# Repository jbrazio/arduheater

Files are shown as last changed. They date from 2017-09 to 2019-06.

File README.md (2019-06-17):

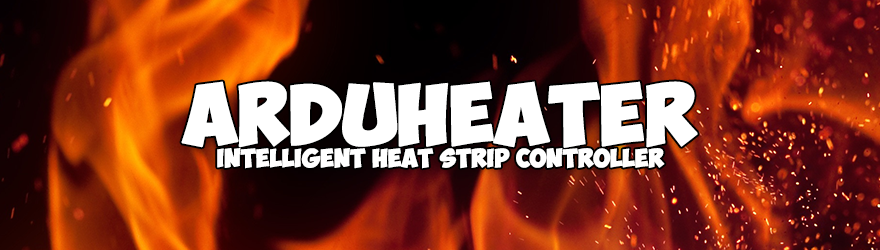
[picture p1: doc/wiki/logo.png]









# Arduheater
Arduheater is a full open source intelligent heat strip controller for astronomy usage.

# Motivation
Controlling dew is a big thing if you really intent to do astronomy all year around.
This project will allow you to build a four channel intelligent heat strip contoller for less than 10€.

# Design Goals

## 1. Remotely controllable
This was a very important part of the design, most heat controllers, specially the DIY ones, rely on the PWM signal for each channel being manually adjusted by means of a potentiometer. This either requires the user to be near the device tweeking it or to set it to a temperature that may be higher than the one really needed thus completely trashing efficiency. Arduheater uses a serial connection so you can use any USB-Serial-TTL dongle to adjust it's settings either you're 2 or 2000 meters away.

## 2. Efficient energy usage
Manual adjusted heater will either require the user to be tweeking it or they will wast more energy than necessary due to the general tendency to use a higher that required setpoint, this is valid for any PWM or bang-bang style controllers. Arduheater uses a temperature sensor (DHT22) to measure basic environmental properties such as temperature and humidity, knowing them both makes the calculation of the dew point[1] possible. Arduheater also has a temperature sensor (NTC) for each heating strip, allowing the micro-controller to have a rough estimation of the temperature the equipment is at; it will be a rough estimation because we are really interested on the lenses surface temperature but we are actually measuring the heat strip temperature, to mitigate this, Arduheater allows the user to set specific offsets per heating strip.

Arduheater uses a PID controller[2] to efficiently manage the energy so only the required amount of energy to maintain a temperature setpoint is delivered to the heating strip. This is possible due the usage of a PWM signal while driving the outputs; the delta between the environmental dew point (plus offset, i.e. setpoint) and the heating strip temperature will make the micro-controller output a PID-calculated PWM signal until this delta reaches zero. In practical terms if a 12V heating strip full on consumes 12W of power (1A) it may be possible for it to use only 1W or even less to keep the equipment above dewpoint and the power usage will be automatically updated during the night as conditions vary, so the system will be always using the least amount of power to keep the dew away.

[1] Dew point is that dreadful threshold at which water condensation starts to happen on the lenses/equipment.

[2] A proportional–integral–derivative controller (PID controller) is a control loop feedback mechanism (controller) commonly used in industrial control systems.

## 3. Builder friendly
Using off-the-shelf components such as the Arduino Nano and easily available parts Arduheater is aimed to be build by anyone with a soldering iron and some patience, no degree in electronics required.

## 4. Multiple independent channels
Each of the four outputs have independent controls such as offset, min and max output power and of course the three main properties of the PID controller (Kp, Ki and Kd).

# Hardware
It was built on top of a standard ATmega 328 Arduino such as UNO, Pro or Nano; currently it does not support the Mega or any other ARM based board.

## BOM

Qty  | Value     | Device              | Size   | Package
---: | :-------- | :------------------ | :----- | :------
1    | Nano 328P | Arduino             |        |
1    | 10uF      | Capacitor Polarized | "Ø5x11 | THT
1    | AM2320    | Probe               |        | THT
4    | 100nF     | Capacitor Ceramic   | 3216   | SMD
4    | 1K        | Resistor            | 3216   | SMD
4    | 1N4004    | Diode               |        | DO41
4    | IRF3205   | N-MOSFET            |        | TO220
4    | EL817     | Optocoupler         |        | DIP4
4    | Red       | LED 3mm             |        | THT
4    | 10K       | NTC                 |        | THT
4    | M+F kit   | XLR                 | 12mm   | GX12
5    | 2P        | Screw Terminal      | 5mm    | THT
8    | 220R      | Resistor            | 3216   | SMD
9    | 10K       | Resistor            | 3216   | SMD

Note: It is *very* important to have a inline fuse on the 12V feed line.

## 3D printed parts
To download and print instructions for the 3D printed parts have a look at the [Thing #2614341][2614341].

[2614341]: https://www.thingiverse.com/thing:2614341

## PCB and Schematic
For the complete Eagle files have a look at the [PCB](./doc/pcb/) folder, as an alternative you may perfer to build the [Preforated Board](./doc/prefboard/) version.

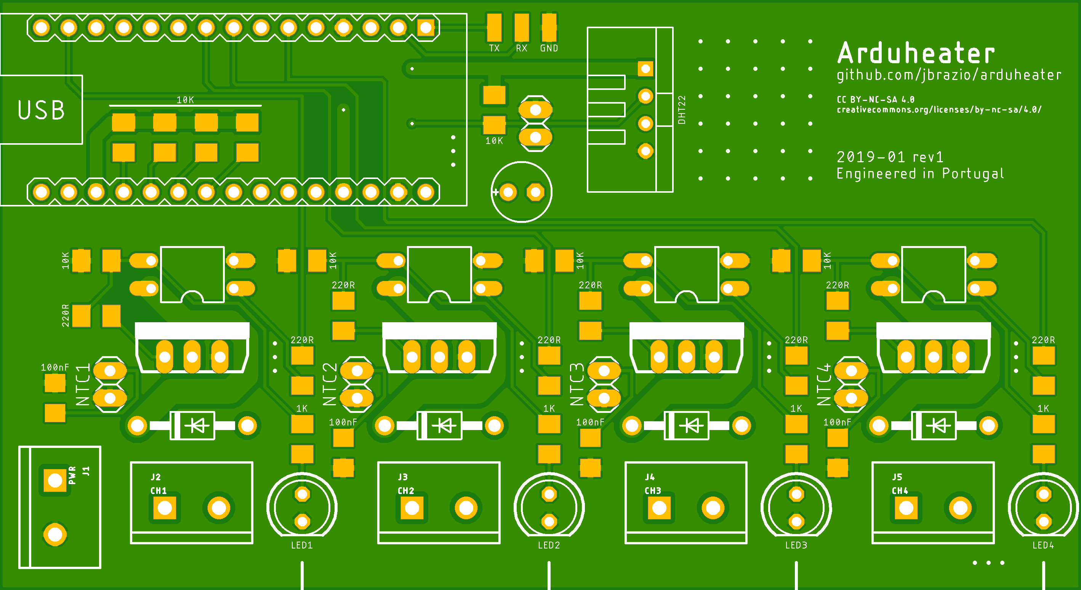
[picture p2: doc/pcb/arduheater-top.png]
PCB Top View


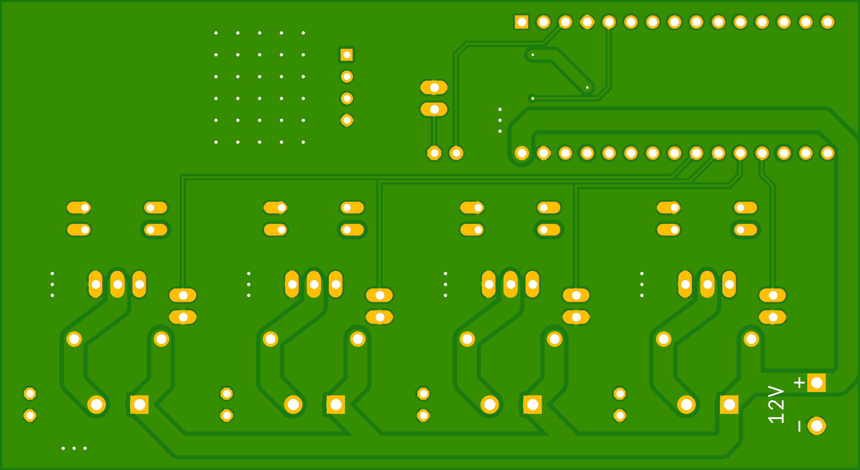
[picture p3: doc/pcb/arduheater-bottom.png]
PCB Bottom View


# License
[GNU GPLv3](./LICENSE).

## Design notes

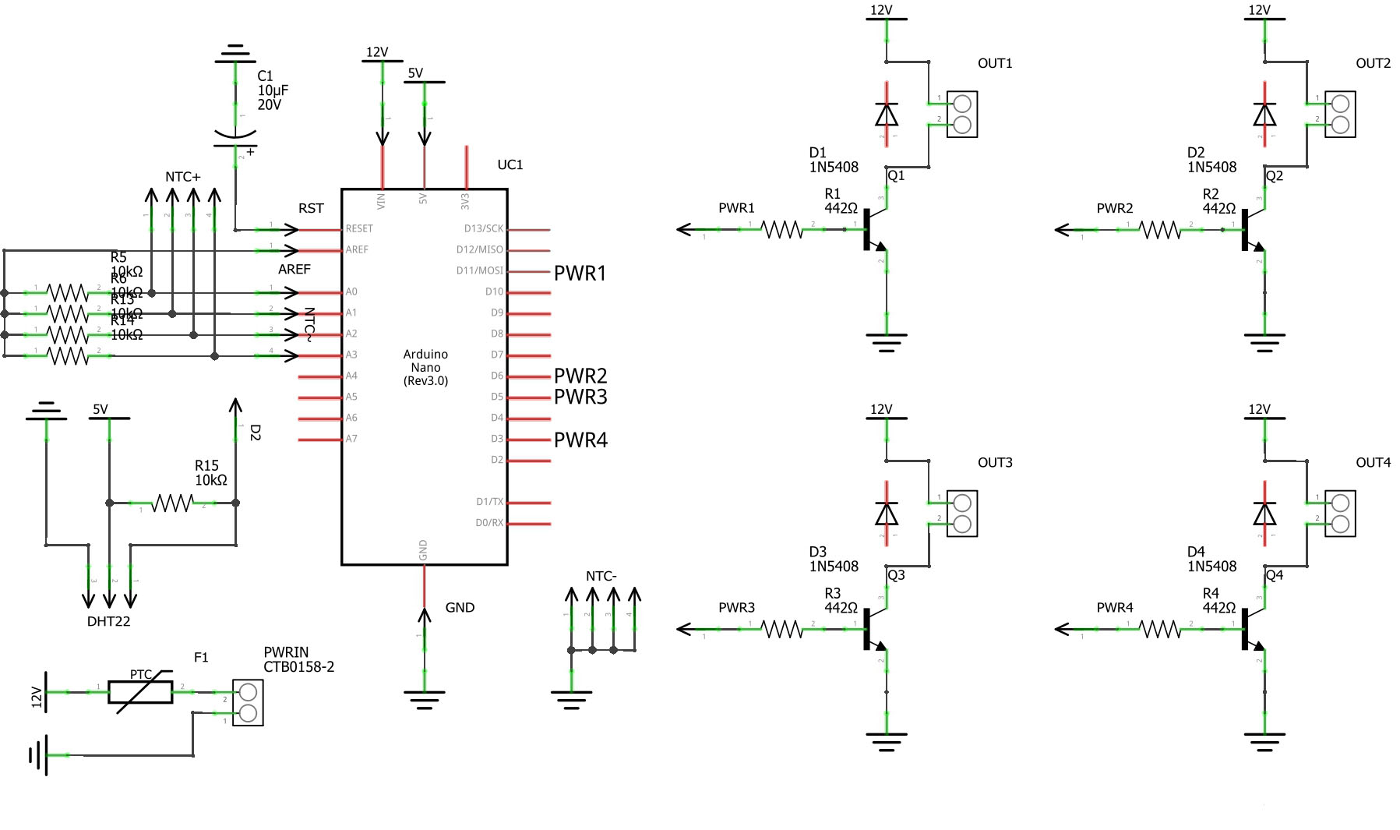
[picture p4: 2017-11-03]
doc/prefboard/arduheater-schematic.jpg

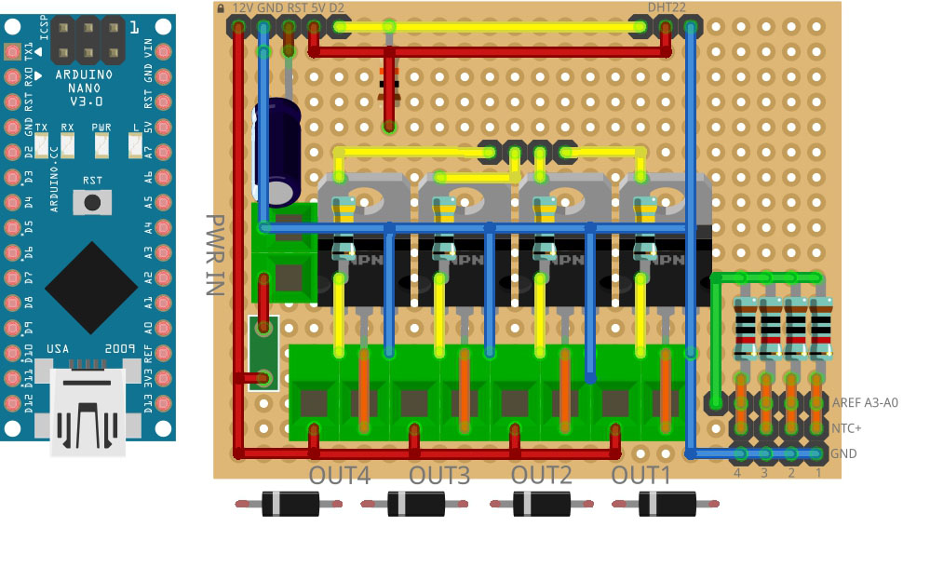
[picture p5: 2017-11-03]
doc/prefboard/arduheater-layout.jpg

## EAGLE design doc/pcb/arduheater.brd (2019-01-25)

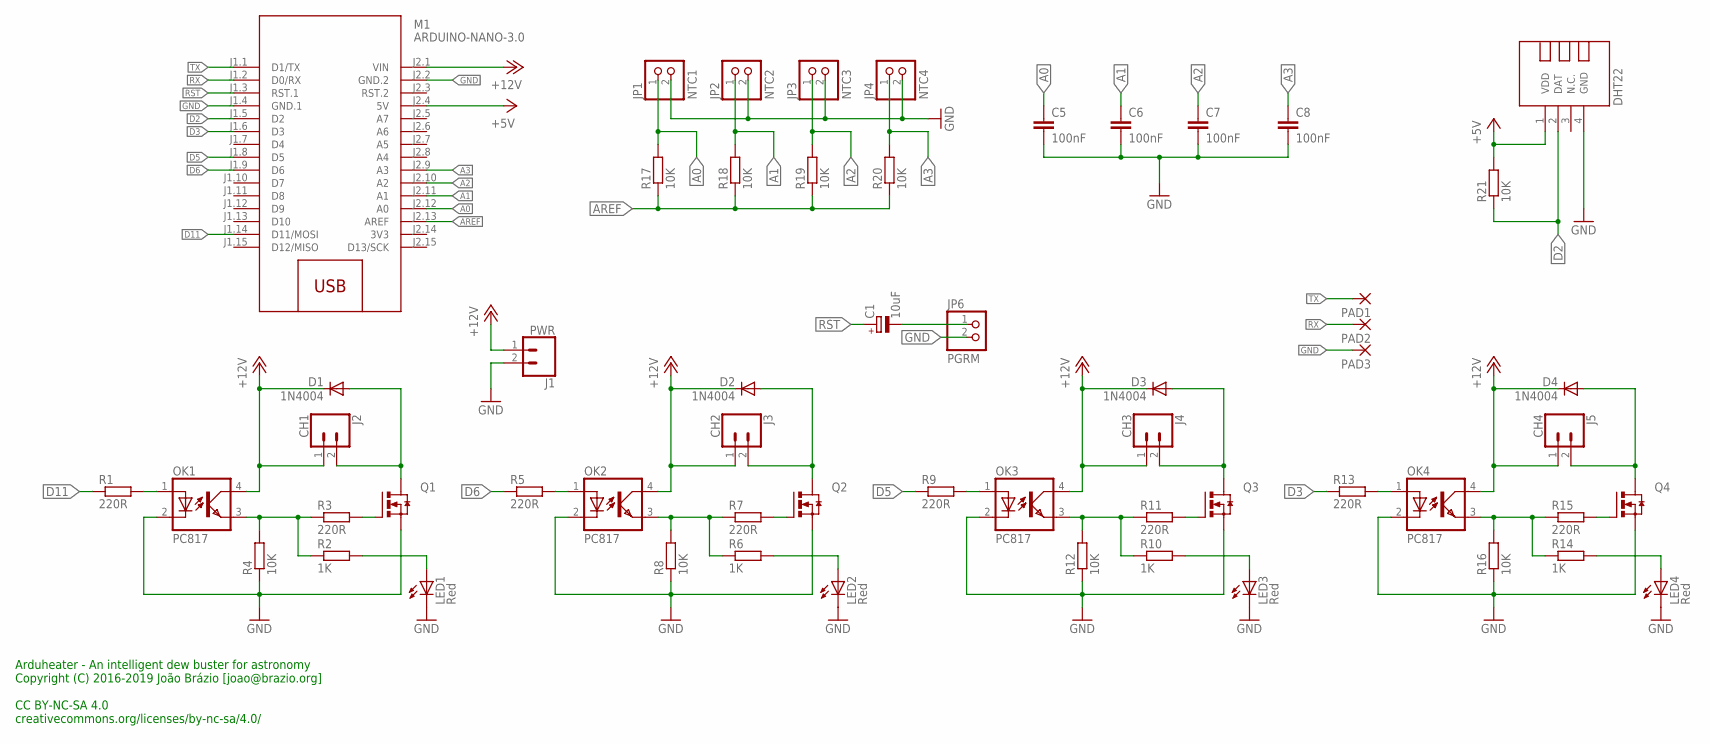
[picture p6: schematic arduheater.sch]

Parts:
C1: 10uF; E2,5-6E
C5, C6, C7, C8: 100nF; C3216
D1, D2, D3, D4: 1N4004; DO41-10
DHT22: TEMP-HUM-SENSOR-DHT22
J1: PWR; SCREWTERMINAL-5MM-2
J2: CH1; SCREWTERMINAL-5MM-2
J3: CH2; SCREWTERMINAL-5MM-2
J4: CH3; SCREWTERMINAL-5MM-2
J5: CH4; SCREWTERMINAL-5MM-2
JP1: NTC1; 1X02
JP2: NTC2; 1X02
JP3: NTC3; 1X02
JP4: NTC4; 1X02
JP6: PGRM; 1X02
LED1, LED2, LED3, LED4: Red; LED5MM
M1: ARDUINO-NANO-3.0
OK1, OK2, OK3, OK4: PC817; DIL04
PAD1, PAD2, PAD3: SMD2; SMD1,27-2,54
Q1, Q2, Q3, Q4: IRF3704L-V; TO262-V
R1, R3, R5, R7, R9, R11, R13, R15: 220R; M1206
R2, R6, R10, R14: 1K; M1206
R4, R8, R12, R16, R17, R18, R19, R20, R21: 10K; M1206

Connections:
3V3: M1.J2.14 (3V3)
+5V: DHT22.1 (VDD), M1.J2.4 (5V), R21.2
+12V: D1.C, D2.C, D3.C, D4.C, J1.1, J2.1, J3.1, J4.1, J5.1, M1.J2.1 (VIN), OK1.4 (COL), OK2.4 (COL), OK3.4 (COL), OK4.4 (COL)
A0: C5.1, JP1.1, M1.J2.12 (A0), R17.2
A1: C6.1, JP2.1, M1.J2.11 (A1), R18.2
A2: C7.1, JP3.1, M1.J2.10 (A2), R19.2
A3: C8.1, JP4.1, M1.J2.9 (A3), R20.2
AREF: M1.J2.13 (AREF), R17.1, R18.1, R19.1, R20.1
D2: DHT22.2 (DAT), M1.J1.5 (D2), R21.1
D3: M1.J1.6 (D3), R13.1
D5: M1.J1.8 (D5), R9.1
D6: M1.J1.9 (D6), R5.1
D11: M1.J1.14 (D11/MOSI), R1.1
GND: C5.2, C6.2, C7.2, C8.2, DHT22.4 (GND), J1.2, JP1.2, JP2.2, JP3.2, JP4.2, JP6.2, LED1.K (C), LED2.K (C), LED3.K (C), LED4.K (C), M1.J1.4 (GND.1), M1.J2.2 (GND.2), OK1.2 (C), OK2.2 (C), OK3.2 (C), OK4.2 (C), PAD3.1, Q1.3 (S), Q2.3 (S), Q3.3 (S), Q4.3 (S), R4.1, R8.1, R12.1, R16.1
unnamed: OK1.1 (A), R1.2
unnamed: Q1.1 (G), R3.2
unnamed: OK2.1 (A), R5.2
unnamed: OK1.3 (EMIT), R2.1, R3.1, R4.2
unnamed: LED2.A, R6.2
unnamed: D1.A, J2.2, Q1.2 (D)
unnamed: OK2.3 (EMIT), R6.1, R7.1, R8.2
unnamed: Q2.1 (G), R7.2
unnamed: C1.-, JP6.1
unnamed: D2.A, J3.2, Q2.2 (D)
unnamed: OK3.1 (A), R9.2
unnamed: LED3.A, R10.2
unnamed: OK3.3 (EMIT), R10.1, R11.1, R12.2
unnamed: Q3.1 (G), R11.2
unnamed: D3.A, J4.2, Q3.2 (D)
unnamed: OK4.1 (A), R13.2
unnamed: LED4.A, R14.2
unnamed: OK4.3 (EMIT), R14.1, R15.1, R16.2
unnamed: Q4.1 (G), R15.2
unnamed: D4.A, J5.2, Q4.2 (D)
unnamed: LED1.A, R2.2
RST: C1.+, M1.J1.3 (RST.1)
RX: M1.J1.2 (D0/RX), PAD2.1
TX: M1.J1.1 (D1/TX), PAD1.1

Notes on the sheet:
DHT22
Arduheater - An intelligent dew buster for astronomy Copyright (C) 2016-2019 João Brázio [joao@brazio.org] CC BY-NC-SA 4.0 creativecommons.org/licenses/by-nc-sa/4.0/

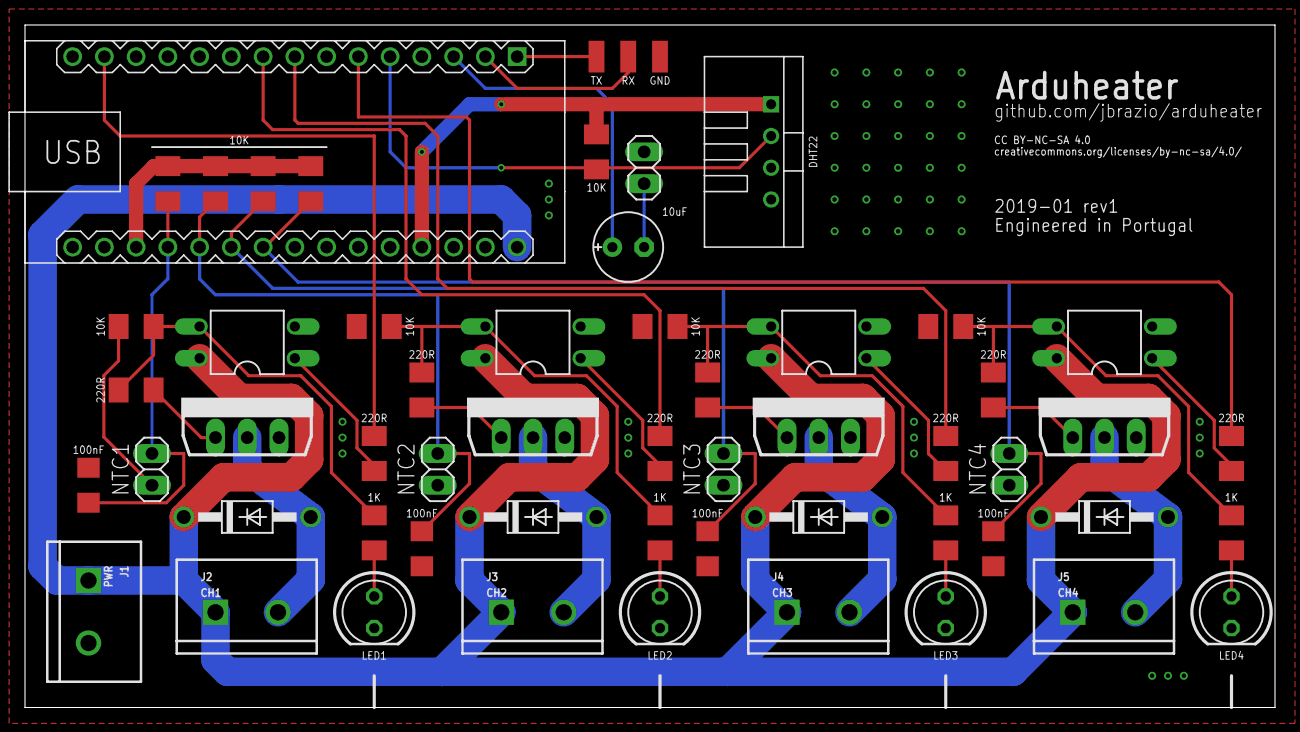
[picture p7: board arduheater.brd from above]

Board: 2 copper layers, 100.0 x 54.6 mm, 57 parts (0 on the bottom side), 37 nets.

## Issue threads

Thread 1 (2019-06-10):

Missing parts

Ultimaboot, 2019-06-10:
Hello,

I can not find the following parts:

**PCB vs BOM:**
C 10pF not found on PCB, is this the component between nano and DHT22?
C 4,7uF not found on PCB, is this the component between nano and DHT22?
ESP32 not found on PCB.
SPX1117 or IRF3205 used?
AM2320 or DHT22 used?
What are the TX, RX and GND for?
On the backside of the box there is a opening for the USB, the other one is for the power i asuming. What connector is used?

**3D print:**
I only have the box file but not the top of the box.

With Regards,

Peter Boot

jbrazio, 2019-06-17:
Hi @Ultimaboot, I was out for the last week.
The [Thingiverse page](https://www.thingiverse.com/thing:2614341) has been updated with all the required STL files. I've also update the [BOM list](https://github.com/jbrazio/arduheater/blob/master/README.md#bom) with the correct part numbers and values.

The MOSFET in use is the IRF3205.
Nevermind the ESP32, SPX1117 parts.
The TX, RX and GND are just a test pads which break out the Arduino serial.

The power cable is directly attached to the `J1` connector which is a screw terminal.

jbrazio, 2019-06-17:
The AM2320 and the DHT22 are interchangable.

Ultimaboot, 2019-06-17:
Hey thanks for the update.
I Thought you were on vacation, no problem. Everyone has the right to
vacation.

Op ma 17 jun. 2019 om 11:18 schreef João Brázio <notifications@github.com>:

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

Ultimaboot, 2019-06-17:
Hey thanks for the update.
I Thought you were on vacation, no problem. Everyone has the right to vacation.

Closed 2019-06-17.

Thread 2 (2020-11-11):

inline fuse on the 12V feed line

Ultimaboot, 2020-11-11:
Hello,
question about inline fuse on the 12V feed line.
How big should the fuse be? And what part do you recommend for a the PTC Resetable Fuse?

Thanks, your doing a great job.

With Regards

Peter Boot

jbrazio, 2020-11-12:
Hi Peter,

It depends on the true load of each heating strip, but considering 1A max per channel using 4 channels, a 4A inline fuse should be enough. I believe the fuss around the PTC would not worth the effort, usually all 12V astronomy equipment is protected by a standard blow-type fuse.

Ultimaboot, 2020-11-14:
Thanks for the reply.
Just waiting for some parts and than i'am gone to build the Arduheater

jbrazio, 2020-11-19:
Actually I do have a frontend application for Arduheater, [check it out here](https://github.com/jbrazio/arduheater-gui-win). You will need Visual Studio 2019 to compile it into a binary or you can download a [pre build version from here](https://cld.pt/dl/download/aabb8fdf-5333-4c93-b34f-9bbf01024b24/0.2019.3.7.zip).

Closed 2020-11-19.

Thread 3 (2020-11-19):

Testing Arduheater

Ultimaboot, 2020-11-19:
I have completed the build of the Arduheater.
I made a connector with led indicator for the 12V. But when i put the USB arduino to the computer the led indicator is turned on.
So somehow the usb is feeding the 12V connector. That can not be right.  Futher i'am still waiting for the NTC sensor, so the are not connected at this time. Can this be causing this? How do i test if everthing is working? can give direction. I have a multimeter to check voltage i you give me directions

With Regards,
Peter

jbrazio, 2020-11-19:
Where do you have the LED connected to ? VCC and GND of the 12V rail ?

Ultimaboot, 2020-11-19:
On nothing.
New update i have on 4 of the 3 outgoing channels 12V and red the red leds on the PCB is turning on. its going on and out some time and i see the green led on the arduino going on and off.
channel 1 is giving 0.08V.

With Regards
Peter

Ultimaboot, 2020-12-06:
Well some help would be appreciated. De Arduheater Win program is working and I'm getting the environment reading.
Ambient, Humidity and dewpoint is working. The ambient temperature is higher than the the Dewpoint temperature. Nothing is heating but that's good I think. How can I test the heater? Can I force the software to heat the heating strip or can you give some voltage measurements to see if everything working correct. I'm not sure at this moment if anything is working.

With Regards

Peter

jbrazio, 2021-02-21:
Sorry to get back so late to you,
Where you able to test it ?

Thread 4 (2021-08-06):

(Feature-) Request about heating control

Fux2, 2021-08-06:
Hi João,
thanks for this great project.
For the rain sensors of my weather station I am looking for a heating control. The arduheater hardware fits perfect, as I need 4 channels.
One dew heating channel for the rain sensing sensor and three heating channels for keep the temperature above freezing.
Is there already something build in, to keep the temperature stable above a given adjustable minimum temperature, for example 3°C? If no, do you think this would be a big effort?
Many thanks
Markus

Fux2, 2021-08-08:
I had some look into the source and think the easiest solution for anti-freezing is, to set the "dew-point" fix to 0°C.
This means, that with the offset dew temperature the target temperature above 0°C can be adjusted.

```
ORIGINAL
  for(size_t i = 0; i < asizeof(output); i++) {
    if(ambient.is_connected()) {
      // Update the output setpoint as long as it is connected.
      output[i].set_setpoint(ambient.dew_point());
      //if(i == 1 || i == 3) output[i].set_setpoint_offset(10);
      //output[i].set_setpoint(40);
```
MODIFIED ch1 to ch3 as anti-freezing heater
  for(size_t i = 0; i < asizeof(output); i++) {
    if(ambient.is_connected()) {
      // Update the output setpoint as long as it is connected.
	if(i == 0) { // default dew mode
		output[i].set_setpoint(ambient.dew_point());
	}
	else { // anti-freezing mode --> "dew_point" always set to 0°C
		output[i].set_setpoint(0.0f);
	}
      //if(i == 1 || i == 3) output[i].set_setpoint_offset(10);
      //output[i].set_setpoint(40);
```
Not tested yet. Any comments are welcome.

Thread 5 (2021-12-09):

Add optional support for SH1106 OLED

jrsphoto, 2021-12-09:
While designing an enclosure for my Adruheater, I designed an alternative cover that includes mounting space for a [SH1106](https://www.amazon.com/Display-Serial-Arduino-Raspberry-DIYmall/dp/B073VD6W1H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) OLED display.  The I2C pins on the Nano are A5 & A4, which your conveniently not using, and I simply added connection to A4/A5 and 3.3v/GND connections.  pretty simple.

My thinking was it would be nice to have the display show current temp/humidity/dew point and channel status.

jrsphoto, 2021-12-09:
It's not fancy but this is the case:  https://a360.co/3ycqrrV

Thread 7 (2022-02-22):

Outdated readme?

pardovot, 2022-02-22:
According to the PCB schematics I can see that it says "DHT22", while in the components list states "AM2320", though I'm not sure how different they are..

I believe you had multiple versions and PCB's, so maybe the BOM wasn't updated accordingly?
I currently own the AM2320, should I replace it to DHT22?

Thanks.

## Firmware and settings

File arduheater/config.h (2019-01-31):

/**
 * Arduheater - An intelligent dew buster for astronomy
 * Copyright (C) 2016-2019 João Brázio [joao@brazio.org]
 *
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
 */

#ifndef __CONFIG_H__
#define __CONFIG_H__

// ----------------------------------------------------------------------------
// Activate debug -------------------------------------------------------------
// ----------------------------------------------------------------------------
#define DEBUG
#define SCOPE_DEBUG


// ----------------------------------------------------------------------------
// OUTPUT CHANNEL configuration -----------------------------------------------
// ----------------------------------------------------------------------------
// Pins  5 and  6: controlled by timer0
// Pins  9 and 10: controlled by timer1
// Pins 11 and  3: controlled by timer2

#define CHANNEL1_OUTPUT 11 // PWM
#define CHANNEL1_SENSOR 0  // Analog

#define CHANNEL2_OUTPUT 6  // PWM
#define CHANNEL2_SENSOR 1  // Analog

#define CHANNEL3_OUTPUT 5  // PWM
#define CHANNEL3_SENSOR 2  // Analog

#define CHANNEL4_OUTPUT 3  // PWM
#define CHANNEL4_SENSOR 3  // Analog


// ----------------------------------------------------------------------------
// AMBIENT SENSOR configuration -----------------------------------------------
// ----------------------------------------------------------------------------
#define AMBIENT_SENSOR_TYPE DHT22 // Select the ambient sensor type
#define AMBIENT_SENSOR_PIN      2 // Digital PIN where ther sensor is connected

#define AMBIENT_SENSOR_T_LPF_ALPHA  0.3F  // Select a value between 0 and 1 where
                                          // 0 disables the sensor's temperature low
                                          // pass filter.

#define AMBIENT_SENSOR_H_LPF_ALPHA  0.8F  // Select a value between 0 and 1 where
                                          // 0 disables the sensor's humidity low
                                          // pass filter.

#define USE_NOAA_DEW_FUNCTION             // NOAA dew func will give you precision at
                                          // the cost of speed.

// WARNING: If you need to change any of the following options it is suggested
//          to open a support ticket[1] first.
//
// [1]: https://github.com/jbrazio/arduheater/issues
#define AMBIENT_SENSOR_ERROR_THRESHOLD 10  // Tolerable number of consecutive errors


// ----------------------------------------------------------------------------
// THERMISTOR configuration ---------------------------------------------------
// ----------------------------------------------------------------------------
// The directives bellow have standard values for the most used NTC thermistor
// type, if you need to tweak them bare in mind that all the output channels
// will be impacted.
#define DEFAULT_NTC_NT  25.0F // Nominal temperature
#define DEFAULT_NTC_BC  3950L // B coeficient
#define DEFAULT_NTC_NV 10000L // Nominal value
#define DEFAULT_NTC_SR 10000L // Series resistor value

// You shouldn't need to change the following values, if for some reason you
// really need to please report back[1] to the project team.
//
// [1]: https://github.com/jbrazio/arduheater/issues
#define NTC_MIN_RAW_VALUE     51 // min value to be considered a valid reading ()
#define NTC_MAX_RAW_VALUE    950 // max value to be considered a valid reading (-23C)
#define NTC_ERR_RAW_THRESHOLD 20 // used for min/max edge calculation
#define NTC_MAX_ERRORS        10 // tolerable number of consecutive errors


// EXPERIMENTAL FEATURE
// Please report back[1] to the project team if you experience issues with the
// following directive enabled.
//
// [1]: https://github.com/jbrazio/arduheater/issues
#define ADC_PRESCALER16


// ----------------------------------------------------------------------------
// PID configuration ----------------------------------------------------------
// ----------------------------------------------------------------------------
// The following directives control the default PID values for each component
// of the algorithm, chansing them here requires you to reset to the EEPROM
// to defaults by using the serial command "XXXX".
#define DEFAULT_Kp  10.0F
#define DEFAULT_Ki  00.3F
#define DEFAULT_Kd  00.0F


// ----------------------------------------------------------------------------
// Configuration validation ---------------------------------------------------
// ----------------------------------------------------------------------------
#include "assert.h"

#endif

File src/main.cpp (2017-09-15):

/**
 * Arduheater - Heat controller for astronomy usage
 * Copyright (C) 2016-2017 João Brázio [joao@brazio.org]
 *
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
 */

#include "arduheater.h"

// Global control structures
dht22 amb;
thermistor ntc;
out_t out[NUM_OUTPUTS];
volatile system_t sys;

int main(void)
{
  // --------------------------------------------------------------------------
  // Enable global interrupts -------------------------------------------------
  // --------------------------------------------------------------------------
  sei();


  // --------------------------------------------------------------------------
  // Serial port init routine -------------------------------------------------
  // --------------------------------------------------------------------------

  #if SERIAL_BAUDRATE < 57600
    const uint16_t UBRR0_value = ((F_CPU / (8L * SERIAL_BAUDRATE)) - 1) /2;
    UCSR0A &= ~bit(U2X0); // baud doubler off
  #else
    const uint16_t UBRR0_value = ((F_CPU / (4L * SERIAL_BAUDRATE)) - 1) /2;
    UCSR0A |= bit(U2X0);  // baud doubler on for high baud rates
  #endif

  // set baudrate
  UBRR0H = UBRR0_value >> 8;
  UBRR0L = UBRR0_value;

  // enable rx and tx
  UCSR0B |= bit(RXEN0);
  UCSR0B |= bit(TXEN0);

  // enable interrupt on complete reception of a byte
  UCSR0B |= bit(RXCIE0);


  // --------------------------------------------------------------------------
  // Sensor init --------------------------------------------------------------
  // --------------------------------------------------------------------------
  ntc.init();
  amb.init();


  // --------------------------------------------------------------------------
  // Timer0 ISR init routine --------------------------------------------------
  // --------------------------------------------------------------------------
  // set waveform generation mode to Fast PWM
  TCCR0A |= bit(WGM01) | bit(WGM00);

  // set clock select to 64 (from prescaler)
  TCCR0B |= bit(CS01) | bit(CS00);

  // set overflow interrupt enable
  TIMSK0 |= bit(TOIE0);


  // --------------------------------------------------------------------------
  // Timer1 ISR init routine --------------------------------------------------
  // --------------------------------------------------------------------------
  // set output compare register A to 500Hz
  OCR1A = 0x7D;

  // set waveform generation mode to CTC
  TCCR1B |= bit(WGM12);

  // set clock select to 256 (from prescaler)
  TCCR1B |= bit(CS12);

  // set output compare A match interrupt enable
  TIMSK1 |= bit(OCIE1A);


  // --------------------------------------------------------------------------
  // Timer2 ISR init routine --------------------------------------------------
  // --------------------------------------------------------------------------
  // set waveform generation mode to PWM Phase Correct
  TCCR2A |= bit(WGM20);

  // set clock select to 64 (from prescaler)
  TCCR2B |= bit(CS22);


  // --------------------------------------------------------------------------
  // ADC init routine ---------------------------------------------------------
  // --------------------------------------------------------------------------
  // set ADC prescaler select to 128
  ADCSRA |= bit(ADPS2) | bit(ADPS1) | bit(ADPS0);

  // set ADC Enable
  ADCSRA |= bit(ADEN);

  // set ADC multiplexer selection to internal 1.1V
  ADMUX  |= bit(REFS1) | bit(REFS0);

  #if (NUM_OUTPUTS > 3)
    // set digital input disable register to A4-A5
    DIDR0 |= bit(ADC5D) | bit(ADC4D);
  #elif (NUM_OUTPUTS > 2)
    // set digital input disable register to A3-A5
    DIDR0 |= bit(ADC5D) | bit(ADC4D) | bit(ADC3D);
  #elif (NUM_OUTPUTS > 1)
    // set digital input disable register to A2-A5
    DIDR0 |= bit(ADC5D) | bit(ADC4D) | bit(ADC3D) | bit(ADC2D);
  #elif (NUM_OUTPUTS > 0)
    // set digital input disable register to A1-A5
    DIDR0 |= bit(ADC5D) | bit(ADC4D) | bit(ADC3D) | bit(ADC2D) | bit(ADC1D);
  #endif


  // --------------------------------------------------------------------------
  // Load settings ------------------------------------------------------------
  // --------------------------------------------------------------------------
  eeprom::load();


  // --------------------------------------------------------------------------
  // Startup check ------------------------------------------------------------
  // --------------------------------------------------------------------------
  while (!any_ntc_ready()) {
    millis_t now = utils::millis();
    static millis_t next = now + 5000L;
    if (now > next) {
      serial::println::PGM(PSTR("warn: no outputs available"));
      break;
    } else { utils::delay(1); }
  }

  while (!(sys.sensor & AMBIENT_SENSOR_READY)) {
    millis_t now = utils::millis();
    static millis_t next = now + 10000L;
    if (now > next) {
      serial::println::PGM(PSTR("err: ambient sensor error"));
      halt();
    } else { utils::delay(1); }
  }

  // set the status as running
  sys.state |= RUNNING;
  serial::banner();


  // --------------------------------------------------------------------------
  // Output init --------------------------------------------------------------
  // --------------------------------------------------------------------------
  DDRB |= 0x20; // Enable D13 as output
  for (size_t i = 0; i < NUM_OUTPUTS; i++ ) {
    pinMode(output_pin(i), OUTPUT); // Enable PWM outputs
    if (out[i].config.autostart) {
      serial::print::PGM(PSTR("warn: auto started out"));
      serial::println::uint8(i);
      cmd::enableheater(i);
    }
  }


  // --------------------------------------------------------------------------
  // Watchdog -----------------------------------------------------------------
  // --------------------------------------------------------------------------
  //wdt_enable(WDTO_4S);


  // --------------------------------------------------------------------------
  // Loop routine -------------------------------------------------------------
  // --------------------------------------------------------------------------
  for(;;) {
    wdt_reset();
    serial::process();
  }

  // We should not reach this
  return 0;
}

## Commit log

2017-02-14 Started using namespaces Implemented serial print functions Removed most forced code optimizations
2017-02-14 Stopped inlining all serial print functions
2017-02-15 Started the implementation of widgets Created dummy files for the ADC functionality
2017-02-25 Major changeset, implemented PID
2017-03-14 Rework the card class
    [config.h, main.cpp]
2017-03-16 Heater channel offset prototype
2017-03-17 Major rework branch init
    [assert.h, config.h]
2017-03-20 Implemented a (still) non-working PID autotune
2017-03-21 PID autotune is working
2017-03-28 All offset working, improved PID algorithm
2017-04-11 Fixed the static bug inside PID
    [config.h, main.cpp]
2017-04-13 ISR will now control the heater based on a register flag
2017-04-21 Relaxed the thermistor error detection process
    [config.h]
2017-04-21 PID autotune debug
2017-09-15 Improved PID performance
2017-10-30 Added project's schematic and updated the README file
    [schematic-power.fzz]
2017-11-03 Updated the schematic so the TIP120 is now being driven at full saturation mode
    [schematic-power.fzz]
2018-03-11 Most chuncks of the code are now ready, still missing glue logic between it all
    [schematic-power.fzz]
2019-01-25 Added Eagle PCB and Schematic
    [arduheater.brd, arduheater.fzz, arduheater.sch]
2019-01-31 Update copyright notice
    [arduheater.sch]
2019-06-17 Update README.md
    BOM list updated

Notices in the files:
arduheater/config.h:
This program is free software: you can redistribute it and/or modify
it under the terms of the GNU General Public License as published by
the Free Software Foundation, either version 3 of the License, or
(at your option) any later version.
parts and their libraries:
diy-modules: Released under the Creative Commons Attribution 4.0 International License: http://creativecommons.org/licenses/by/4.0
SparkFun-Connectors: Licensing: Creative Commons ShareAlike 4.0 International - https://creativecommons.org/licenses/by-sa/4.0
